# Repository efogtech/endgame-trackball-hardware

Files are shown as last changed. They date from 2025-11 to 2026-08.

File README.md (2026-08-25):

## Endgame Trackball (hardware)

| Revision | Type | RGB LEDs | Consumption (idle/sleep) | C‑to‑C cable support | Additional exposed pins* | Notes |
|---|---|---|---|---|---|---|
| rev3 | medium batch  | 🔴 | 🔴 480/130 uA | ⚠️ | ❌ | Doesn't support the new (latest) encoders without a firmware modification. |
| rev4 | large batch | 🟢 | 🔴 440/110 uA | ⚠️ | ❌ | — |
| rev5 | transitional  | 🟢 | 🟢 110/60 uA | ✅ | ❌ | Restarts when USB power lost. |
| rev6 | transitional  | 🟢 | 🟢 95/50 uA | ✅ | ⚠️ | The exposed pins are not very convenient to use. |
| rev7 | ~~final~~ | 🟢 | 🟢 95/50 uA | ✅ | ✅ | The AXP2585 charging IC has got discontinued. |
| rev8 | transitional  | 🟢 | ?/? uA | ✅ | ✅ | Specifications are to be measured. Has a [hardware issue](https://www.reddit.com/r/efogtech/comments/1vsg4g9/hardware_issue_disclosure/). Can't work without a battery. |
| rev9 | transitional  | 🟢 | ?/? uA | ✅ | ✅ | Specifications are to be measured. Has the same hardware issue. |
| rev10 | final | 🟢 | ?/? uA | ✅ | ✅ | Not in production yet. |

*Additional 3 GPIOs for arbitrary user modifications. 

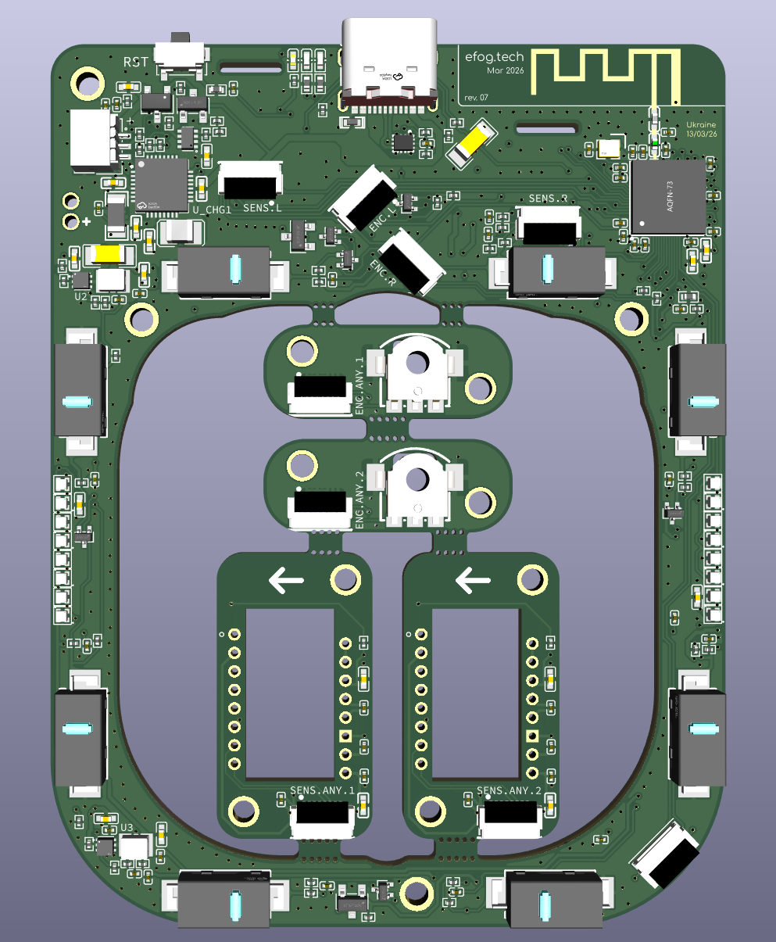
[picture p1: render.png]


#### Why 6 layers?

Because it's cheaper than 4 layers. Yes, seriously.

#### Stackup

JLC06161H-3313

#### Also see

Parent repo: https://github.com/efogtech/endgame-trackball

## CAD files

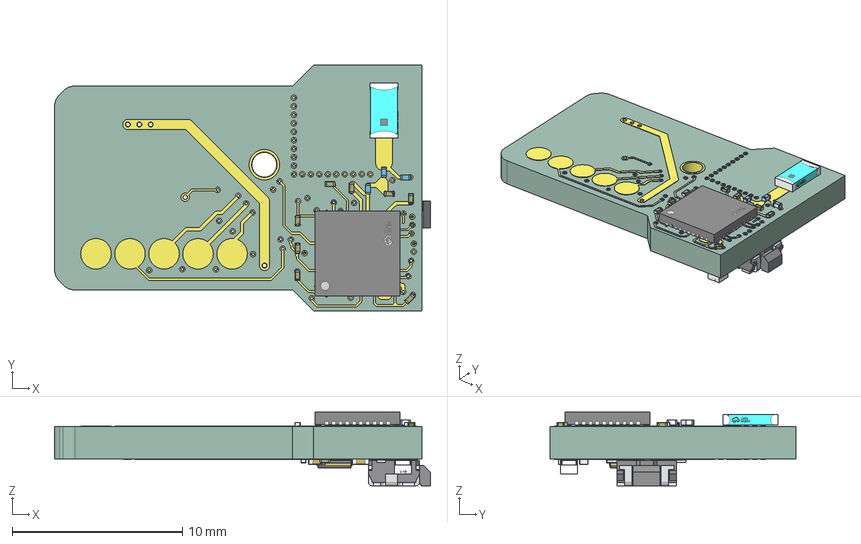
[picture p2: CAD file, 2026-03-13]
dongle-1k/dongle.step
22.1 x 14.4 x 4.33 mm
C0201_L0.6-W0.3-H0.3 x 12
L0201-RD x 3
ANT-SMD-2_L3.2-W1.6-H0.6-C504002
QFN-40_L5.0-W5.0-P0.40-TL-EP3.6
C0402_L1.0-W0.5-H0.5 x 3
CRYSTAL-SMD_4P-L2.0-W1.6-BL
SW-SMD_HX-TSC4A-250GF-DZ
LED-SMD_4P-L1.0-W1.0-TL_XL-1010RGBC-WS2812B
dongle_copper
dongle_via
dongle_PCB

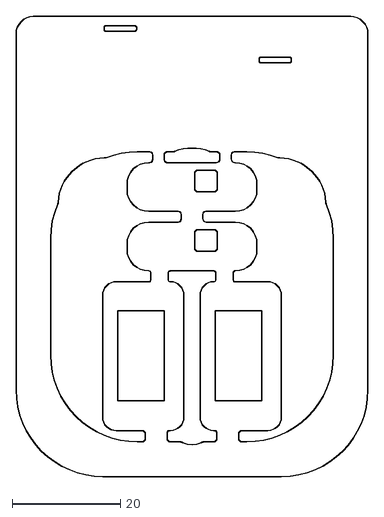
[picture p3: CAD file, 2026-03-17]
trackball-Edge_Cuts.dxf
65.0 x 85.0

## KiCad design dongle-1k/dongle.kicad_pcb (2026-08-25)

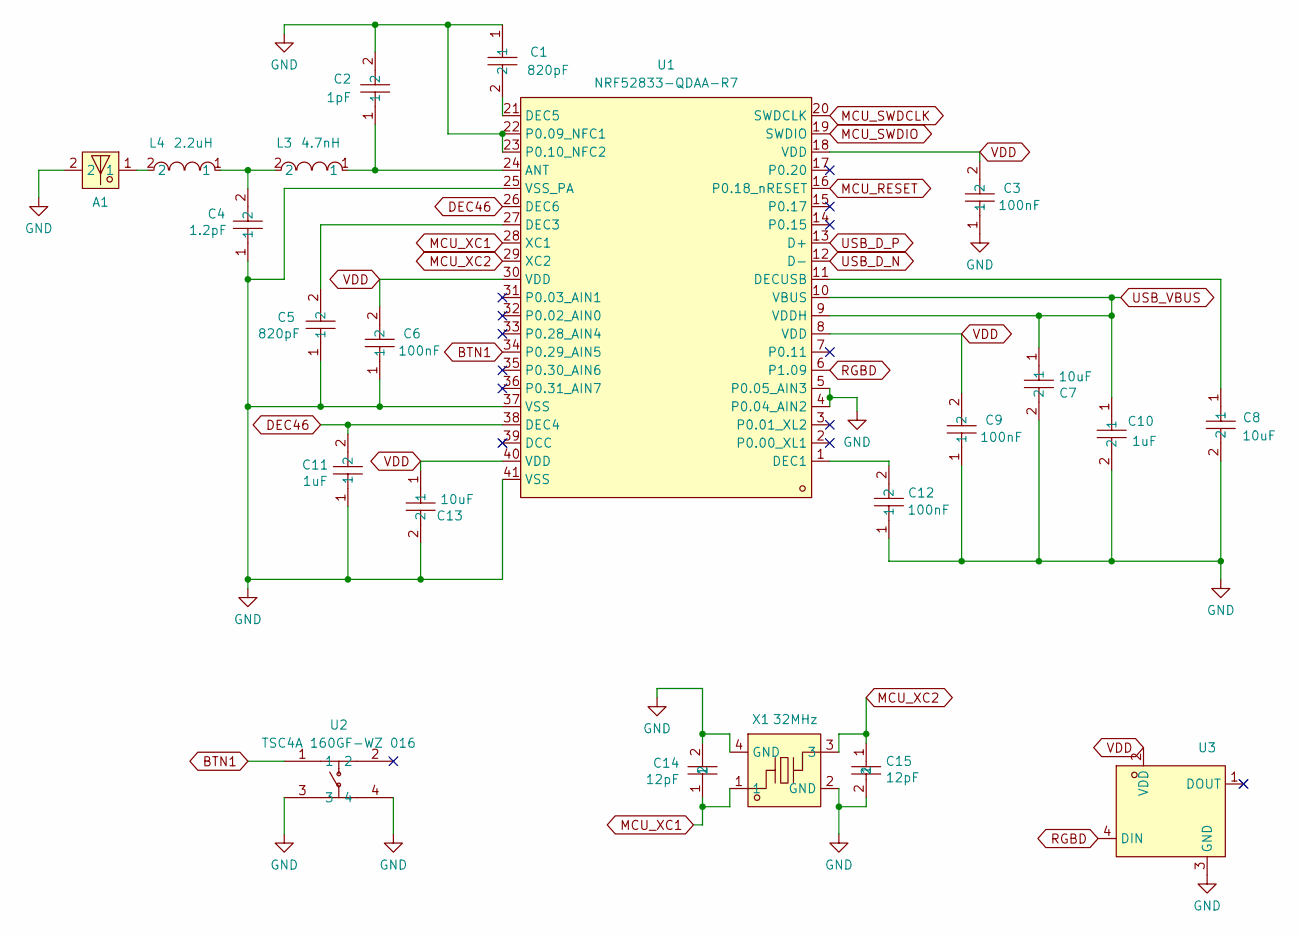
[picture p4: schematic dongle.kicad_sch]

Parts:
A1: mifa-2.4ghz-fr4-2.0mm
C1, C5: 0201B821K500NT; C0201; LCSC Part C2836759
C2: 0201CG1R0C250NT; C0201; LCSC Part C301901
C3, C6, C9, C12: CGA0201X5R104K100ET; C0201; LCSC Part C6119757
C4: CGA0201C0G1R2C500ET; C0201; LCSC Part C22374839
C7, C8, C13: CL05A106MP5NUNC_C315248; C0402; LCSC Part C315248
C10, C11: CGA0201X5R105M6R3ET; C0201; LCSC Part C6119749
C14, C15: 0201CG120J500NT; C0201; LCSC Part C50391
L3: LQP03HQ4N7H02D; L0201; LCSC Part C237443
L4: LQP03HQ2N2H02D; L0201; LCSC Part C1329438
U1: NRF52833-QDAA-R7; QFN-40_L5.0-W5.0-P0.40-TL-EP3.6; LCSC Part C3007767
U2: TSC4A 160GF-WZ 016; KEY-SMD_TSC4A; LCSC Part C2906284
U3: XL-1010RGBC-WS2812B; LED-SMD_4P-L1.0-W1.0-TL_XL-1010RGBC-WS2812B; LCSC Part C5349953
X1: XL7EL89CKI-111YLC-32M; CRYSTAL-SMD_4P-L2.0-W1.6-BL; LCSC Part C2965582

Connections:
BTN1: U1.34 (P0.29_AIN5), U2.1
DEC46: C11.2, U1.26 (DEC6), U1.38 (DEC4)
GND: A1.2, C1.1, C2.2, C3.1, C4.1, C5.1, C6.1, C7.2, C8.2, C9.1, C10.2, C11.1, C12.1, C13.2, C14.2, C15.2, U1.4 (P0.04_AIN2), U1.5 (P0.05_AIN3), U1.22 (P0.09_NFC1), U1.23 (P0.10_NFC2), U1.25 (VSS_PA), U1.37 (VSS), U1.41 (VSS), U2.3, U2.4, U3.1 (DOUT), U3.3 (GND), X1.2 (GND), X1.4 (GND)
MCU_RESET: U1.16 (P0.18_nRESET)
MCU_SWDCLK: U1.20 (SWDCLK)
MCU_SWDIO: U1.19 (SWDIO)
MCU_XC1: C14.1, U1.28 (XC1), X1.1
MCU_XC2: C15.1, U1.29 (XC2), X1.3
unnamed: A1.1, L4.2
unnamed: C4.2, L3.2, L4.1
unnamed: C2.1, L3.1, U1.24 (ANT)
unnamed: C12.2, U1.1 (DEC1)
unnamed: C5.2, U1.27 (DEC3)
unnamed: C1.2, U1.21 (DEC5)
unnamed: C8.1, U1.11 (DECUSB)
RGBD: U1.6 (P1.09), U3.4 (DIN)
USB_D_N: U1.12 (D-)
USB_D_P: U1.13 (D+)
USB_VBUS: C7.1, C10.1, U1.9 (VDDH), U1.10 (VBUS)
VDD: C3.2, C6.2, C9.2, C13.1, U1.8 (VDD), U1.18 (VDD), U1.30 (VDD), U1.40 (VDD), U3.2 (VDD)

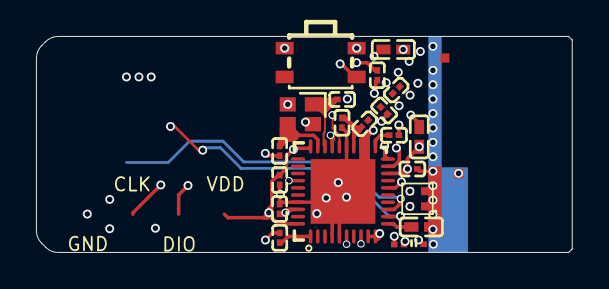
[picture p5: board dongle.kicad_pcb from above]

Board: 6 copper layers, 29.8 x 12.0 mm, 22 parts (0 on the bottom side), 15 nets.

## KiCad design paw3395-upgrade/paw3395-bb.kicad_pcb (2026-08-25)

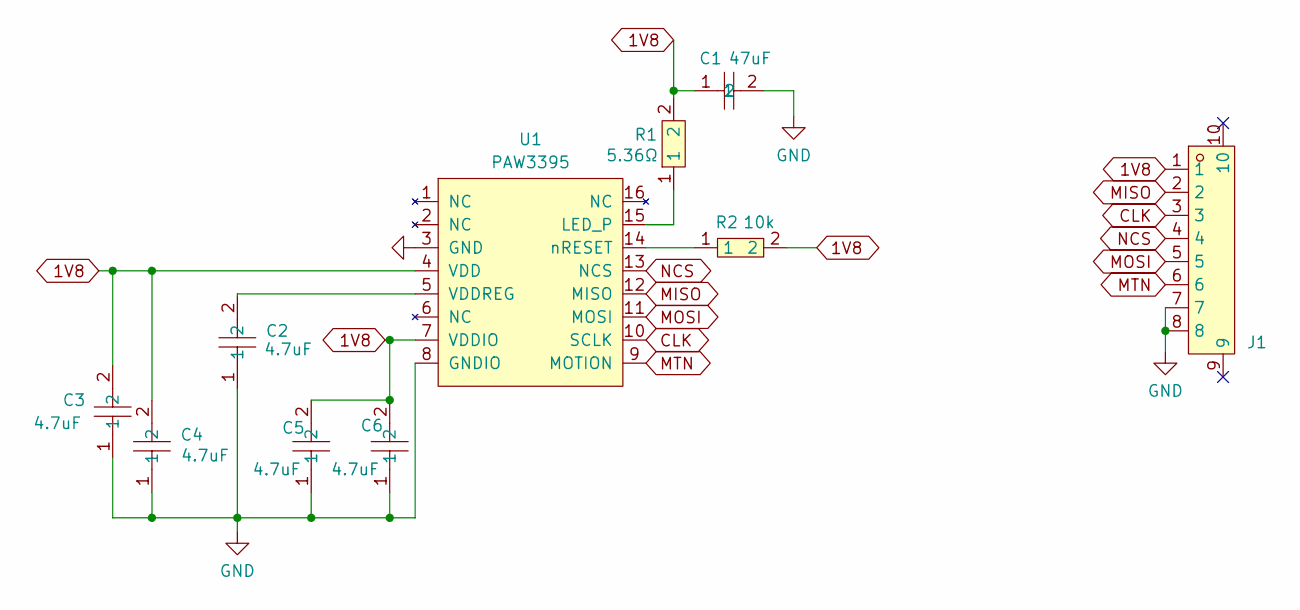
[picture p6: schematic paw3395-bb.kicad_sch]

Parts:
C1: GRM188R60J476ME15D; C0603; LCSC Part C140782
C2, C3, C4, C5, C6: GRM035R60J475ME15D; C0201; LCSC Part C335103
J1: AFH34-S08FIA-1H; FPC-SMD_8P-P0.50_JS_AFH34-S08FIA-1H; LCSC Part C5139822
R1: C49254122; R0402; LCSC Part C49254122
R2: RC-01W103JT; R0201; LCSC Part C304504
U1: PAW3395

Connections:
1V8: C1.1, C3.2, C4.2, C5.2, C6.2, J1.1, R1.2, R2.2, U1.4 (VDD), U1.7 (VDDIO)
CLK: J1.3, U1.10 (SCLK)
GND: C1.2, C2.1, C3.1, C4.1, C5.1, C6.1, J1.7, J1.8, U1.3 (GND), U1.8 (GNDIO)
MISO: J1.2, U1.12 (MISO)
MOSI: J1.5, U1.11 (MOSI)
MTN: J1.6, U1.9 (MOTION)
NCS: J1.4, U1.13 (NCS)
unnamed: R1.1, U1.15 (LED_P)
unnamed: C2.2, U1.5 (VDDREG)
unnamed: R2.1, U1.14 (nRESET)

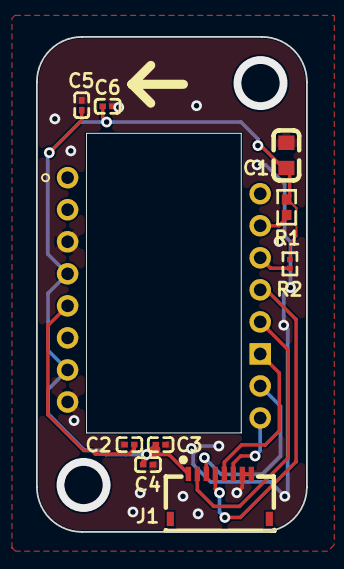
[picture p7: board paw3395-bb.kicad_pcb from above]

Board: 2 copper layers, 15.0 x 27.5 mm, 10 parts (0 on the bottom side), 10 nets.

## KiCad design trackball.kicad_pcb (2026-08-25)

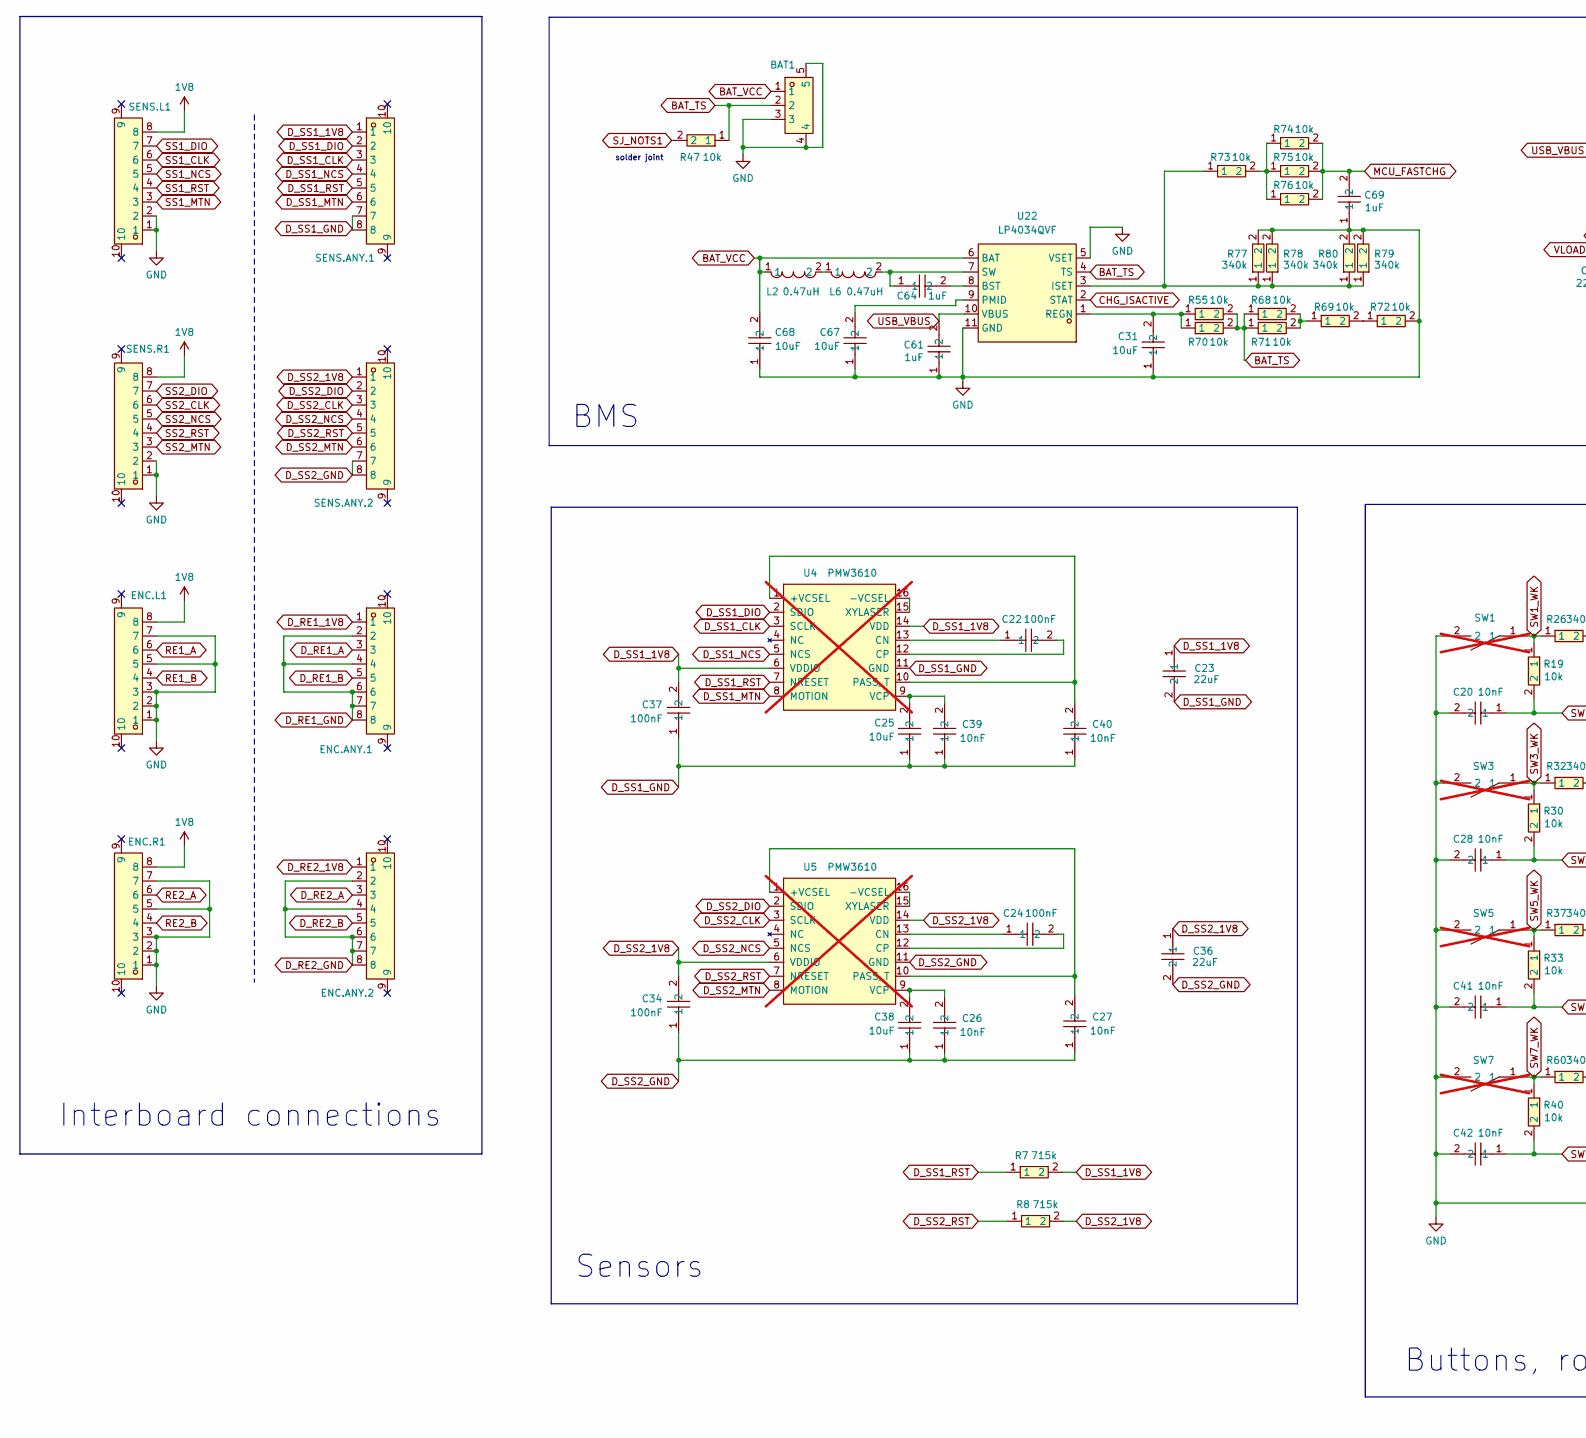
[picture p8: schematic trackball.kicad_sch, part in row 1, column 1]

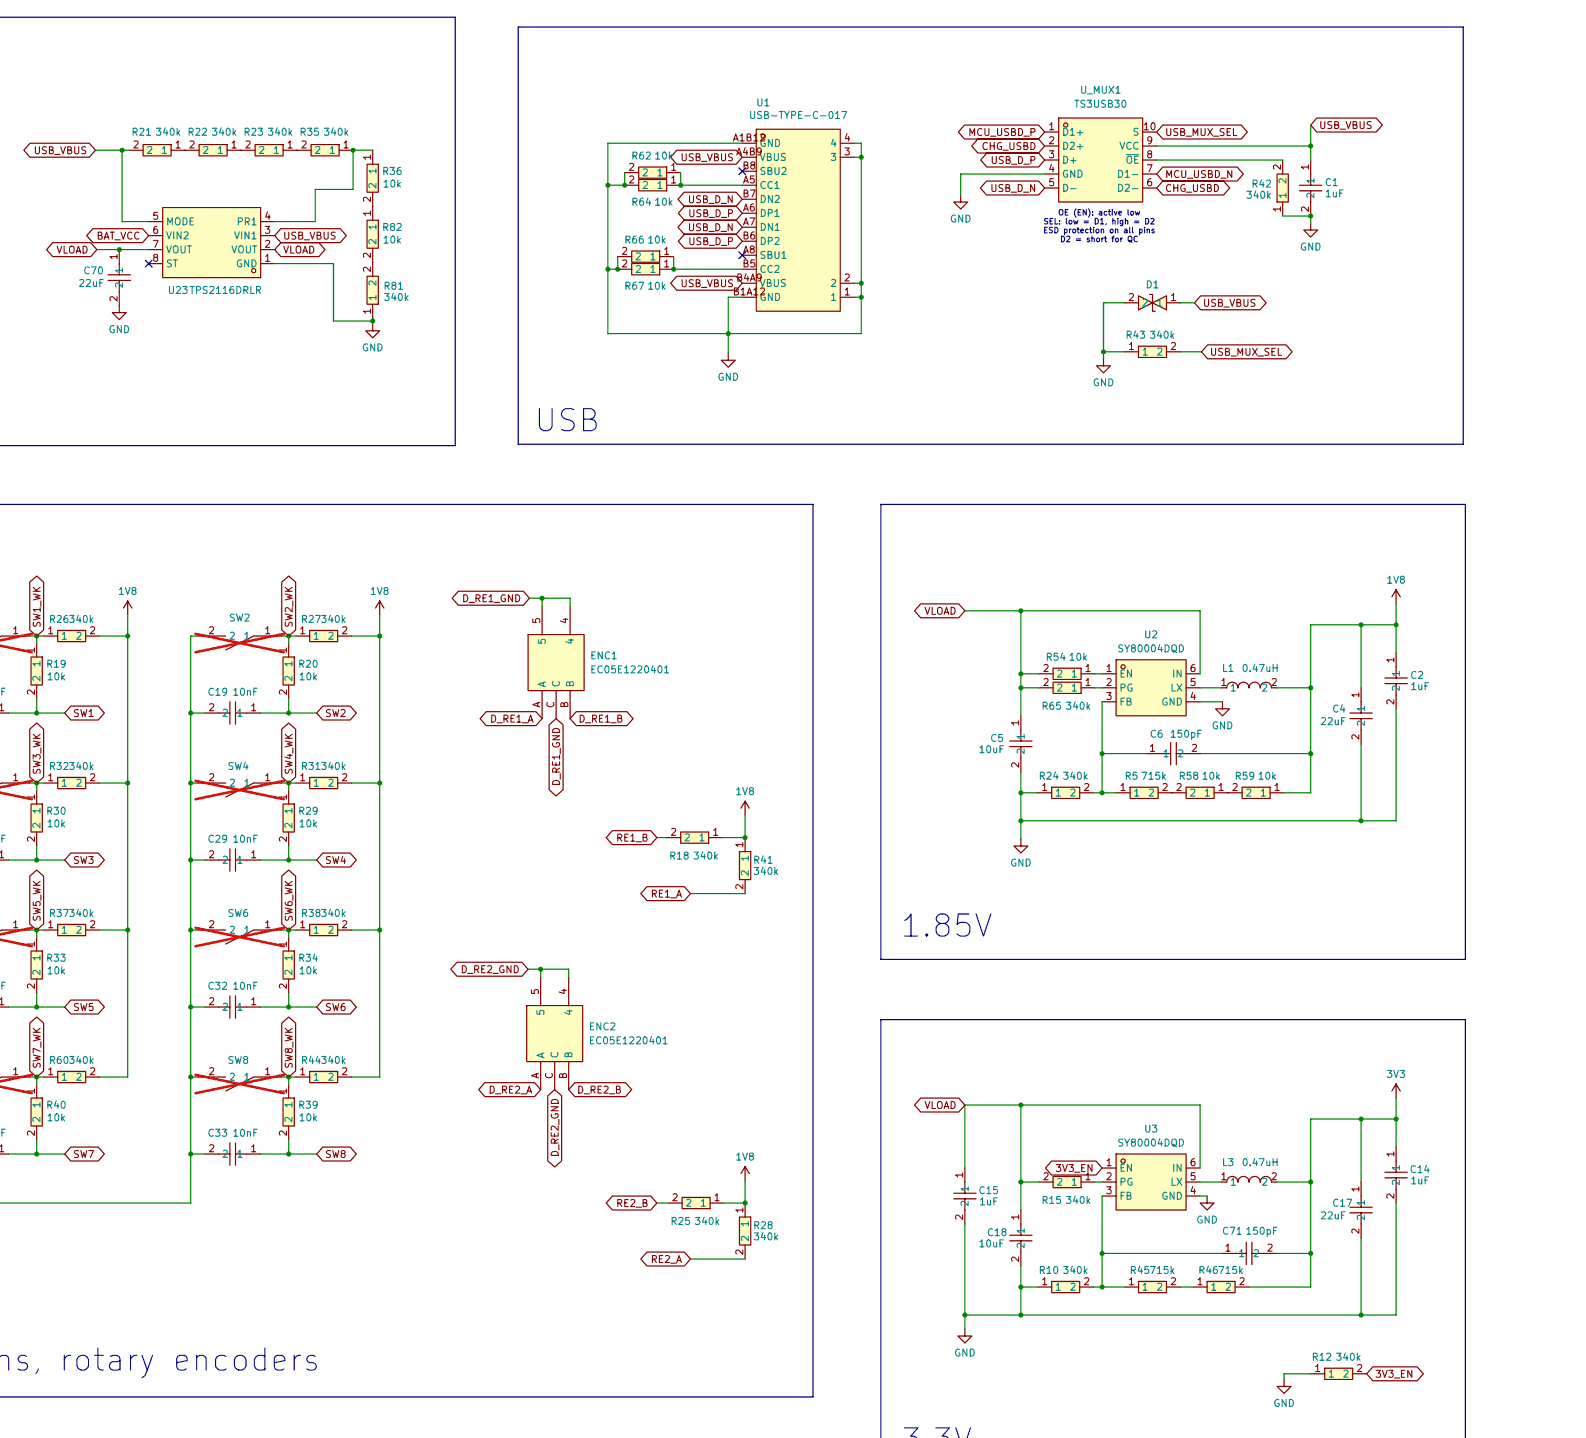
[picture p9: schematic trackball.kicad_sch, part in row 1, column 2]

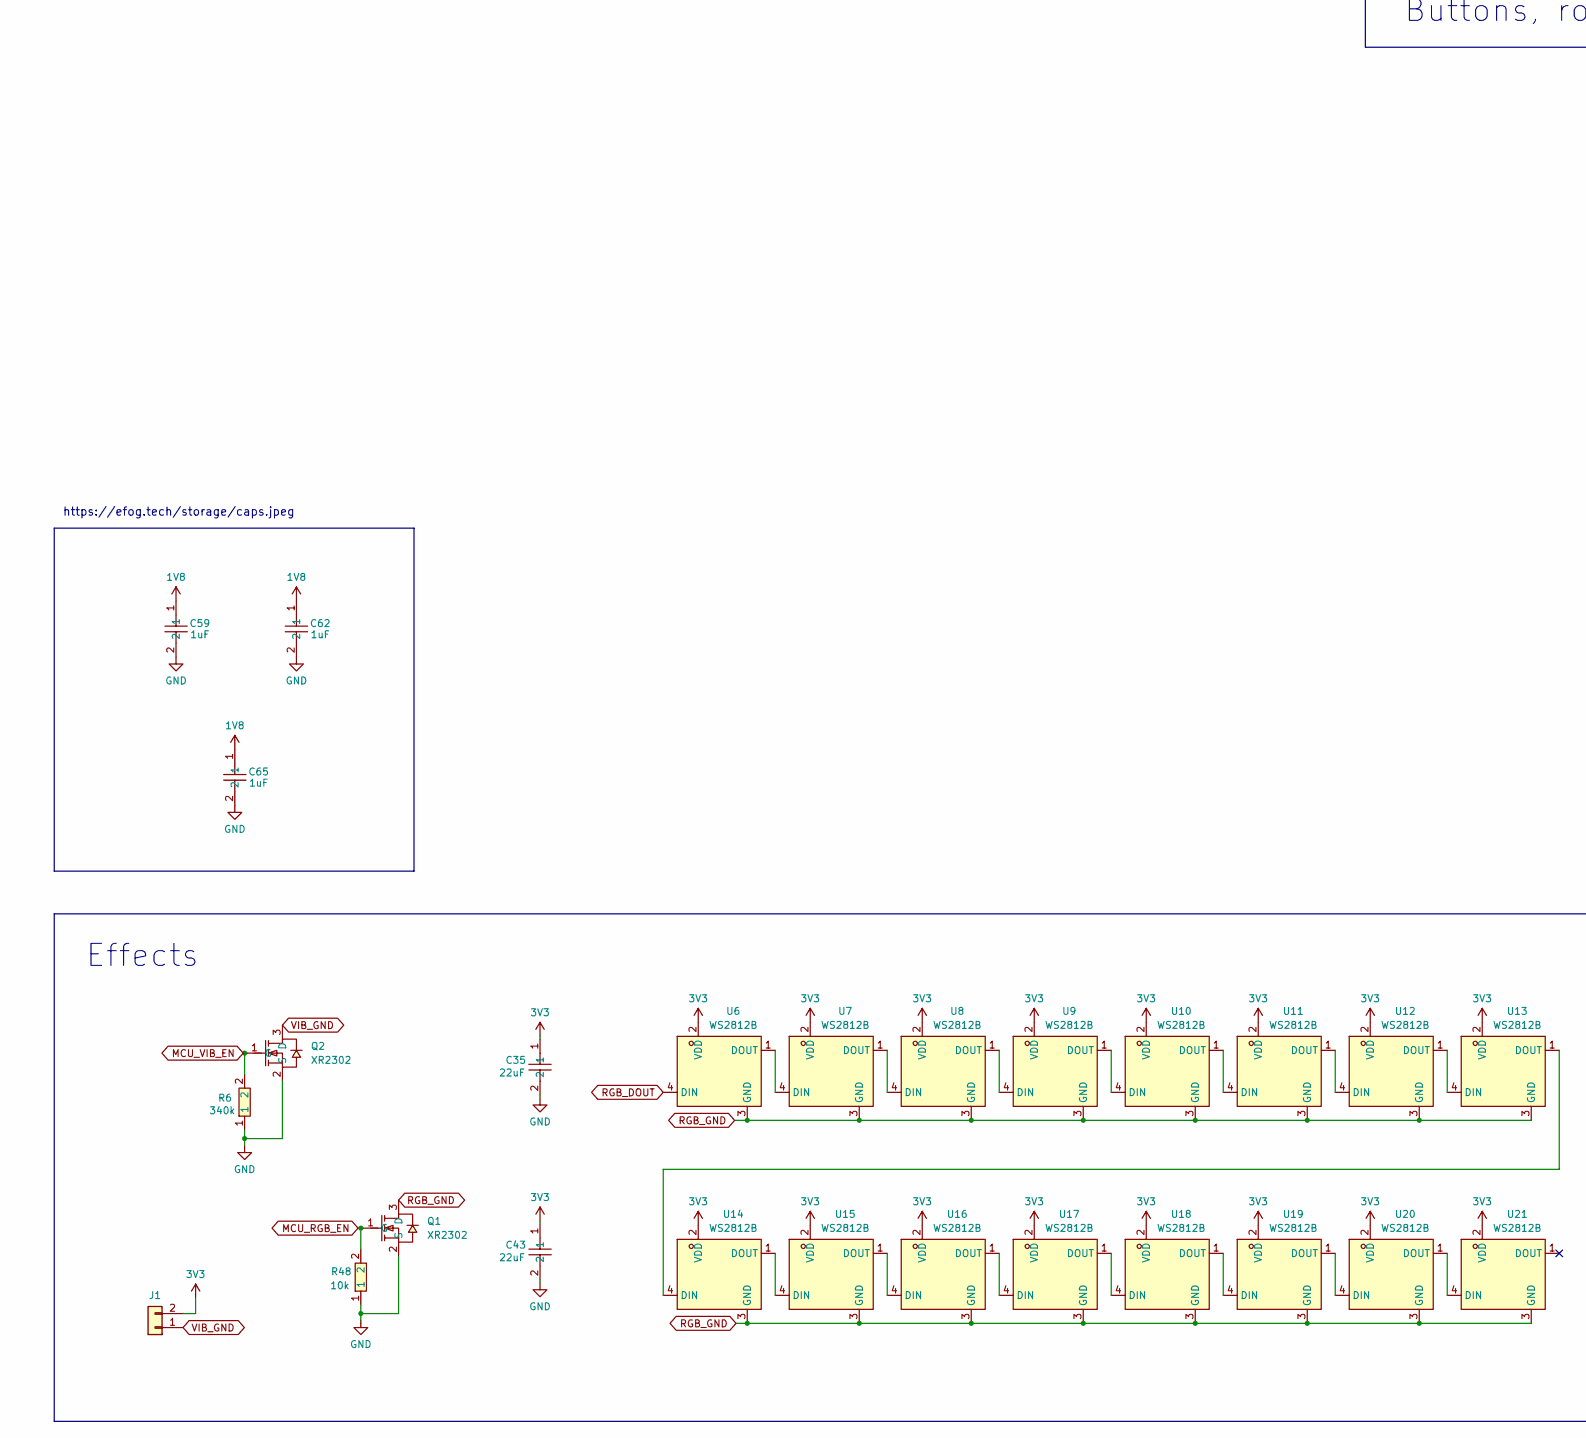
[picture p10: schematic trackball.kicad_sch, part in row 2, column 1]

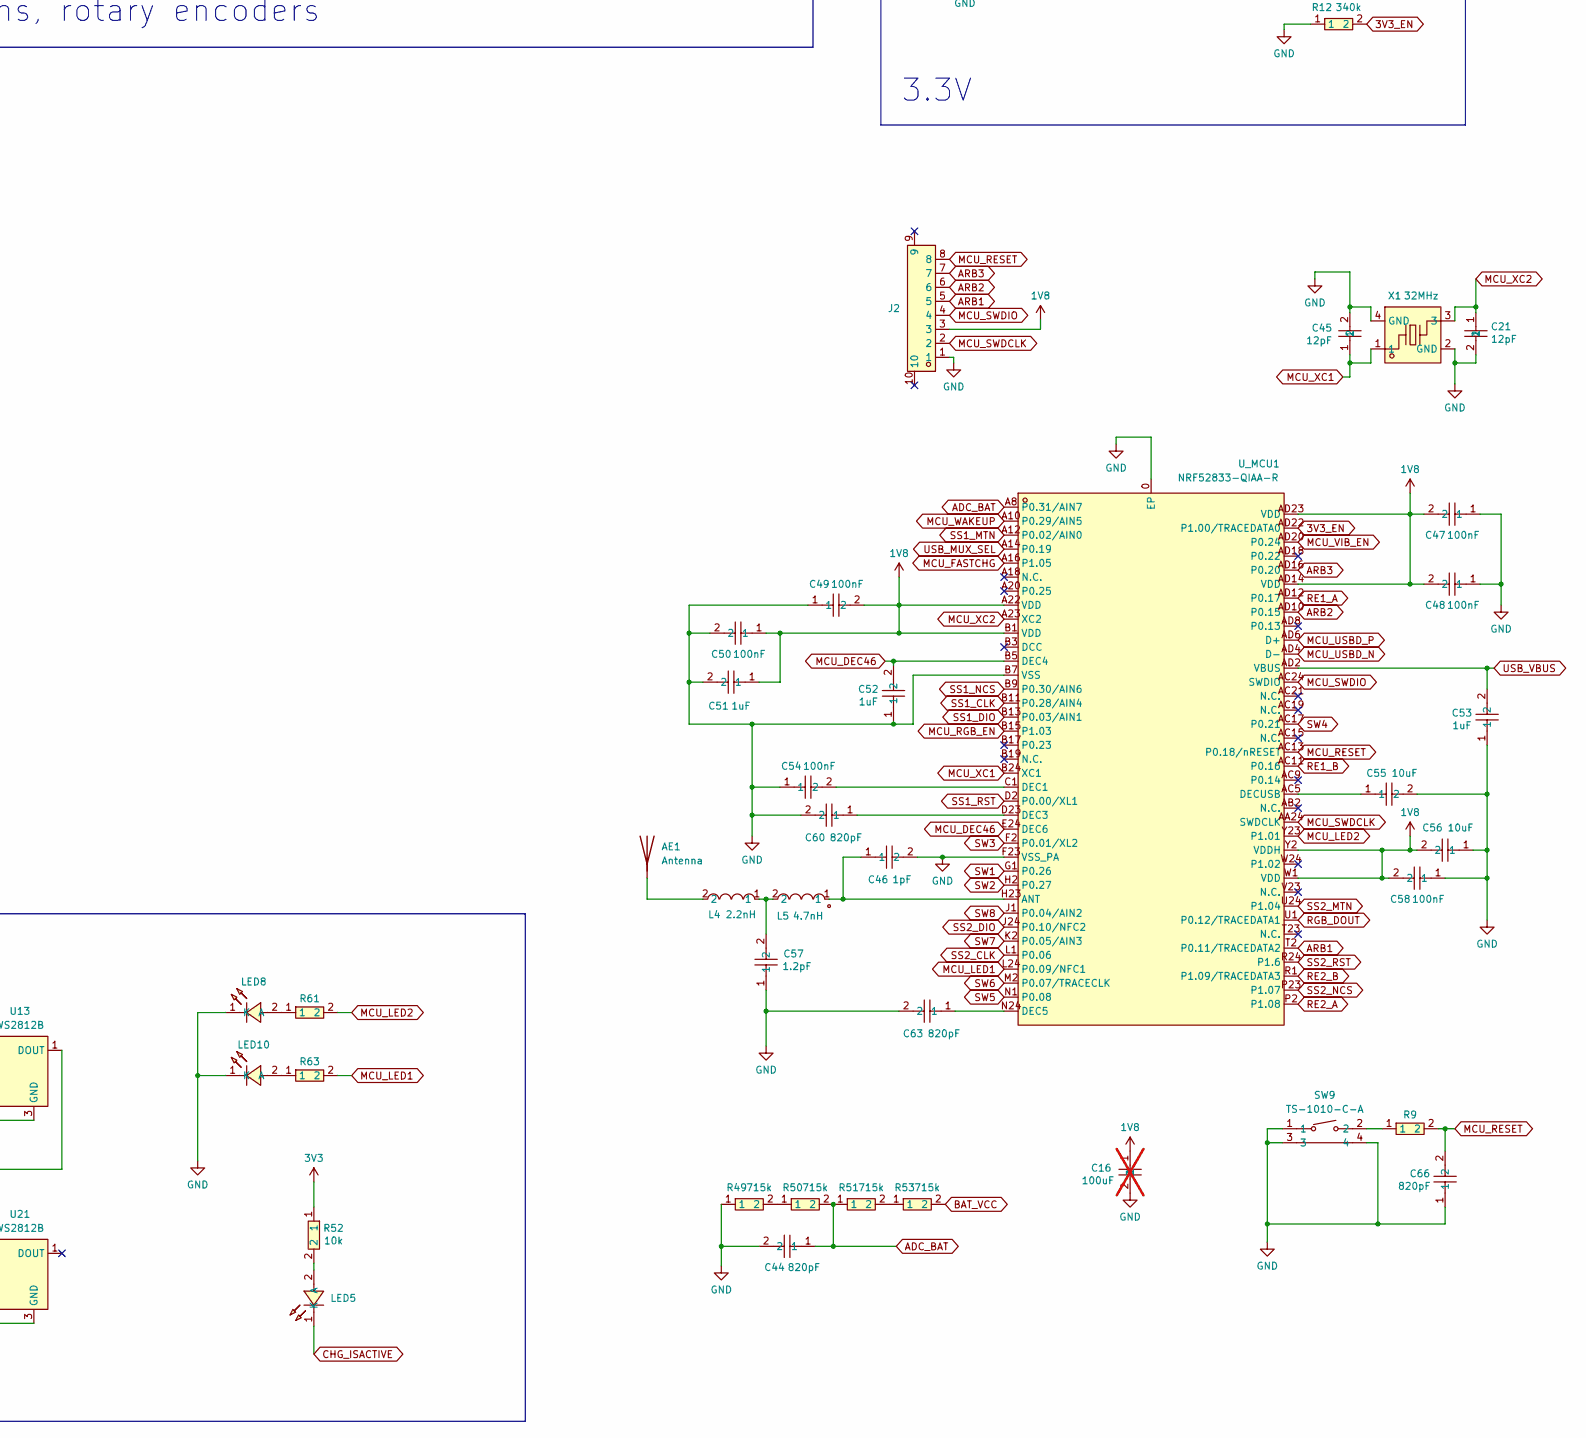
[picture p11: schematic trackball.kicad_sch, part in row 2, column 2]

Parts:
AE1: Antenna; Texas_SWRA117D_2.4GHz_Left
BAT1: HCZZ0032-3; CONN-SMD_HCZZ0032-3; LCSC Part C7433424
C1, C2, C14, C15, C51, C52, C53, C59, C61, C62, C64, C65, C69: CGA0201X5R105M6R3ET; C0201; LCSC Part C6119749
C4, C17, C23, C35, C36, C43, C70: GRM155R60J226ME11D; C0402; LCSC Part C415703
C5, C18, C25, C31, C38, C55, C56, C67, C68: CL05A106MP5NUNC_C315248; C0402; LCSC Part C315248
C6, C71: C0201; LCSC Part C18213206
C16: CL31A107MQHNNNE; C1206; LCSC Part C15008; not fitted
C19, C20, C26, C27, C28, C29, C32, C33, C39, C40, C41, C42: 0201B103K160NT; C0201; LCSC Part C285154
C21, C45: 0201CG120J500NT; C0201; LCSC Part C50391
C22, C24, C34, C37, C47, C48, C49, C50, C54, C58: CGA0201X5R104K100ET; C0201; LCSC Part C6119757
C44, C60, C63, C66: 0201B821K500NT; C0201; LCSC Part C2836759
C46: 0201CG1R0C250NT; C0201; LCSC Part C301901
C57: CGA0201C0G1R2C500ET; C0201; LCSC Part C22374839
D1: 0402ESDA-05N; D0402-BI; LCSC Part C316049
ENC1, ENC2: EC05E1220401; SW-SMD_EC05E1220401; LCSC Part C116648
ENC.ANY.1, ENC.ANY.2, ENC.L1, ENC.R1: AFH34-S08FIA-1H; FPC-SMD_8P-P0.50_JS_AFH34-S08FIA-1H; LCSC Part C5139822
J1: Conn_01x02
J2: AFH34-S08FIA-1H; FPC-SMD_8P-P0.50_JS_AFH34-S08FIA-1H; LCSC Part C5139822
L1, L2, L3, L6: FTC252012SR47MBCA; IND-SMD_L2.5-W2.0; LCSC Part C5832368
L4: LQG15HS2N2S02D; L0402; LCSC Part C86061
L5: LQG15HS4N7S02D; L0402-R-RD; LCSC Part C86065
LED5: XL-1005UGC; LED0402-RD_GREEN; LCSC Part C965793
LED8, LED10: TZ-P2-0402RTIA1-0.45T; LED0402-RD_RED; LCSC Part C779449
Q1, Q2: XR2302; SOT-23-3_L2.9-W1.3-P0.95-LS2.4-BR; LCSC Part C42456447
R5, R7, R8, R45, R46, R49, R50, R51, R53: 715k; R0201; LCSC Part C321023
R6, R10, R12, R15, R18, R21, R22, R23, R24, R25, R26, R27, R28, R31, R32, R35, R37, R38, R41, R42, R43, R44, R60, R65, R77, R78, R79, R80, R81: 0201WMF3403TEE; R0201; LCSC Part C423573
R9, R61, R63: RT0402BRE0750RL; R0402; LCSC Part C853312
R19, R20, R29, R30, R33, R34, R36, R39, R40, R47, R48, R52, R54, R55, R58, R59, R62, R64, R66, R67, R68, R69, R70, R71, R72, R73, R74, R75, R76, R82: 0201WMF1002TEE; R0201; LCSC Part C473048
SENS.ANY.1, SENS.ANY.2, SENS.L1, SENS.R1: AFH34-S08FIA-1H; FPC-SMD_8P-P0.50_JS_AFH34-S08FIA-1H; LCSC Part C5139822
SW1, SW2, SW3, SW4, SW5, SW6, SW7, SW8: HX TC-5608-Y; SW-SMD_TC-5608-Y; LCSC Part C25168853; not fitted
SW9: TS-1010-C-A; KEY-SMD_TX-1010-X-X; LCSC Part C692458
U1: USB-TYPE-C-017; USB-TYPE-C-SMD_C9900008089; LCSC Part C2927037
U2, U3: SY80004DQD; VSON-6_L1.5-W1.5-P0.50-TL; LCSC Part C20617244
U4, U5: PMW3610; not fitted
U6, U7, U8, U9, U10, U11, U12, U13, U14, U15, U16, U17, U18, U19, U20, U21: WS2812B; LED-SMD_4P-L1.0-W1.0-TL_XL-1010RGBC-WS2812B; LCSC Part C5349953
U22: LP4034QVF; DFN-10_L3.0-W3.0-P0.50-BL-EP2.5; MPN LP4034QVF; LCSC Part C42460070
U23: TPS2116DRLR; SOT-583-8_L2.1-W1.6-P0.50-LS1.6-BL; LCSC Part C3235557
U_MCU1: NRF52833-QIAA-R; AQFN-73_L7.0-W7.0-P0.50-BL-EP4.8; LCSC Part C504799
U_MUX1: TS3USB30; UQFN-10_L1.8-W1.4-P0.40-TL; LCSC Part C73880
X1: XL7EL89CKI-111YLC-32M; CRYSTAL-SMD_4P-L2.0-W1.6-BL; LCSC Part C2965582

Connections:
1V8: C2.1, C4.1, C6.2, C16.1, C47.2, C48.2, C49.2, C50.1, C51.1, C56.2, C58.2, C59.1, C62.1, C65.1, ENC.L1.8, ENC.R1.8, J2.3, L1.2, R18.1, R25.1, R26.2, R27.2, R28.1, R31.2, R32.2, R37.2, R38.2, R41.1, R44.2, R59.1, R60.2, SENS.L1.8, SENS.R1.8, U_MCU1.A22 (VDD), U_MCU1.AD14 (VDD), U_MCU1.AD23 (VDD), U_MCU1.B1 (VDD), U_MCU1.W1 (VDD), U_MCU1.Y2 (VDDH); also elsewhere on the board
3V3: C14.1, C17.1, C35.1, C43.1, C71.2, J1.2, L3.2, R46.2, R52.1, U6.2 (VDD), U7.2 (VDD), U8.2 (VDD), U9.2 (VDD), U10.2 (VDD), U11.2 (VDD), U12.2 (VDD), U13.2 (VDD), U14.2 (VDD), U15.2 (VDD), U16.2 (VDD), U17.2 (VDD), U18.2 (VDD), U19.2 (VDD), U20.2 (VDD), U21.2 (VDD)
3V3_EN: R12.2, U3.1 (EN), U_MCU1.AD22 (P1.00/TRACEDATA0)
ADC_BAT: C44.1, R50.2, R51.1, U_MCU1.A8 (P0.31/AIN7)
ARB1: J2.5, U_MCU1.T2 (P0.11/TRACEDATA2)
ARB2: J2.6, U_MCU1.AD10 (P0.15)
ARB3: J2.7, U_MCU1.AD16 (P0.20)
BAT_TS: BAT1.2, R47.1, R55.2, R68.1, R70.2, R71.1, U22.4 (TS)
BAT_VCC: BAT1.1, C68.2, L2.1, R53.2, U22.6 (BAT), U23.6 (VIN2)
CHG_ISACTIVE: LED5.1 (K), U22.2 (STAT)
CHG_USBD: U_MUX1.2 (D2+), U_MUX1.6 (D2-)
D_RE2_A: ENC1.A, ENC.ANY.1.3; also elsewhere on the board
D_RE2_B: ENC1.B, ENC.ANY.1.5; also elsewhere on the board
D_RE2_GND: ENC1.4, ENC1.5, ENC1.C, ENC.ANY.1.2, ENC.ANY.1.4, ENC.ANY.1.6, ENC.ANY.1.7, ENC.ANY.1.8; also elsewhere on the board
D_SS1_1V8: C23.1, C37.2, R7.2, SENS.ANY.1.1, U4.6 (VDDIO), U4.14 (VDD); also elsewhere on the board
D_SS1_CLK: SENS.ANY.1.3, U4.3 (SCLK); also elsewhere on the board
D_SS1_DIO: SENS.ANY.1.2, U4.2 (SDIO); also elsewhere on the board
D_SS1_GND: C23.2, C25.1, C37.1, C39.1, C40.1, SENS.ANY.1.7, SENS.ANY.1.8, U4.11 (GND); also elsewhere on the board
D_SS1_MTN: SENS.ANY.1.6, U4.8 (MOTION); also elsewhere on the board
D_SS1_NCS: SENS.ANY.1.4, U4.5 (NCS); also elsewhere on the board
D_SS1_RST: R7.1, SENS.ANY.1.5, U4.7 (NRESET); also elsewhere on the board
D_SS2_1V8: C34.2, C36.1, R8.2, SENS.ANY.2.1, U5.6 (VDDIO), U5.14 (VDD); also elsewhere on the board
D_SS2_CLK: SENS.ANY.2.3, U5.3 (SCLK); also elsewhere on the board
D_SS2_DIO: SENS.ANY.2.2, U5.2 (SDIO); also elsewhere on the board
D_SS2_GND: C26.1, C27.1, C34.1, C36.2, C38.1, SENS.ANY.2.7, SENS.ANY.2.8, U5.11 (GND); also elsewhere on the board
D_SS2_MTN: SENS.ANY.2.6, U5.8 (MOTION); also elsewhere on the board
D_SS2_NCS: SENS.ANY.2.4, U5.5 (NCS); also elsewhere on the board
D_SS2_RST: R8.1, SENS.ANY.2.5, U5.7 (NRESET); also elsewhere on the board
GND: BAT1.3, BAT1.4, BAT1.5, C1.2, C2.2, C4.2, C5.2, C14.2, C15.2, C16.2, C17.2, C18.2, C19.2, C20.2, C21.2, C28.2, C29.2, C31.1, C32.2, C33.2, C35.2, C41.2, C42.2, C43.2, C44.2, C45.2, C46.2, C47.1, C48.1, C49.1, C50.2, C51.2, C52.1, C53.1, C54.1, C55.2, C56.1, C57.1, C58.1, C59.2, C60.2, C61.1, C62.2, C63.2, C65.2, C66.1, C67.1, C68.1, C69.1, C70.2, D1.2, ENC.L1.1, ENC.L1.2, ENC.L1.3, ENC.L1.5, ENC.L1.7, ENC.R1.1, ENC.R1.2, ENC.R1.3, ENC.R1.5, ENC.R1.7, J2.1, LED8.1 (K), LED10.1 (K), Q1.2 (S), Q2.2 (S), R6.1, R10.1, R12.1, R24.1, R42.1, R43.1, R48.1, R49.1, R62.2, R64.2, R66.2, R67.2, R72.2, R77.2, R78.2, R79.2, R80.2, R81.1, SENS.L1.1, SENS.L1.2, SENS.R1.1, SENS.R1.2, SW1.2, SW2.2, SW3.2, SW4.2, SW5.2, SW6.2, SW7.2, SW8.2, SW9.1, SW9.3, SW9.4, U1.1, U1.2, U1.3, U1.4, U1.A1B12 (GND), U1.B1A12 (GND), U2.4 (GND), U3.4 (GND), U22.5 (VSET), U22.11 (GND), U23.1 (GND), U_MCU1.0 (EP), U_MCU1.B7 (VSS), U_MCU1.F23 (VSS_PA), U_MUX1.4 (GND), X1.2 (GND), X1.4 (GND); also elsewhere on the board
MCU_DEC46: C52.2, U_MCU1.B5 (DEC4), U_MCU1.E24 (DEC6)
MCU_FASTCHG: C69.2, R74.2, R75.2, R76.2, U_MCU1.A16 (P1.05)
MCU_LED1: R63.2, U_MCU1.L24 (P0.09/NFC1)
MCU_LED2: R61.2, U_MCU1.Y23 (P1.01)
MCU_RESET: C66.2, J2.8, R9.2, U_MCU1.AC13 (P0.18/nRESET)
MCU_RGB_EN: Q1.1 (G), R48.2, U_MCU1.B15 (P1.03)
MCU_SWDCLK: J2.2, U_MCU1.AA24 (SWDCLK)
MCU_SWDIO: J2.4, U_MCU1.AC24 (SWDIO)
MCU_USBD_N: U_MCU1.AD4 (D-), U_MUX1.7 (D1-)
MCU_USBD_P: U_MCU1.AD6 (D+), U_MUX1.1 (D1+)
MCU_VIB_EN: Q2.1 (G), R6.2, U_MCU1.AD20 (P0.24)
MCU_WAKEUP: U_MCU1.A10 (P0.29/AIN5); also elsewhere on the board
MCU_XC1: C45.1, U_MCU1.B24 (XC1), X1.1
MCU_XC2: C21.1, U_MCU1.A23 (XC2), X1.3
unnamed: AE1.1 (A_1), L4.2
unnamed: C57.2, L4.1, L5.2
unnamed: ENC2.4, ENC2.5, ENC2.C, ENC.ANY.2.2, ENC.ANY.2.4, ENC.ANY.2.6, ENC.ANY.2.7, ENC.ANY.2.8
unnamed: ENC2.A, ENC.ANY.2.3
unnamed: ENC2.B, ENC.ANY.2.5
unnamed: L2.2, L6.1
unnamed: LED5.2 (A), R52.2
unnamed: LED8.2 (A), R61.1
unnamed: LED10.2 (A), R63.1
unnamed: R5.2, R58.2
unnamed: R9.1, SW9.2
unnamed: R21.1, R22.2
unnamed: R22.1, R23.2
unnamed: R23.1, R35.2
unnamed: R36.2, R82.1
unnamed: R45.2, R46.1
unnamed: R49.2, R50.1
unnamed: R51.2, R53.1
unnamed: R58.1, R59.2
unnamed: R68.2, R69.1, R71.2
unnamed: R69.2, R72.1
unnamed: R73.2, R74.1, R75.1, R76.1
unnamed: R81.2, R82.2
unnamed: R62.1, R64.1, U1.A5 (CC1)
unnamed: R66.1, R67.1, U1.B5 (CC2)
unnamed: R54.1, U2.1 (EN)
unnamed: C6.1, R5.1, R24.2, U2.3 (FB)
unnamed: L1.1, U2.5 (LX)
unnamed: R65.1, U2.2 (PG)
unnamed: C71.1, R10.2, R45.1, U3.3 (FB)
unnamed: L3.1, U3.5 (LX)
unnamed: R15.1, U3.2 (PG)
unnamed: C40.2, U4.1 (+VCSEL), U4.10 (PASS_T)
unnamed: U4.15 (XYLASER), U4.16 (-VCSEL)
unnamed: C22.1, U4.13 (CN)
unnamed: C22.2, U4.12 (CP)
unnamed: C25.2, C39.2, U4.9 (VCP)
unnamed: C27.2, U5.1 (+VCSEL), U5.10 (PASS_T)
unnamed: U5.15 (XYLASER), U5.16 (-VCSEL)
unnamed: C24.1, U5.13 (CN)
unnamed: C24.2, U5.12 (CP)
unnamed: C26.2, C38.2, U5.9 (VCP)
unnamed: U6.1 (DOUT), U7.4 (DIN)
unnamed: U7.1 (DOUT), U8.4 (DIN)
unnamed: U8.1 (DOUT), U9.4 (DIN)
unnamed: U9.1 (DOUT), U10.4 (DIN)
unnamed: U10.1 (DOUT), U11.4 (DIN)
unnamed: U11.1 (DOUT), U12.4 (DIN)
unnamed: U12.1 (DOUT), U13.4 (DIN)
unnamed: U13.1 (DOUT), U14.4 (DIN)
unnamed: U14.1 (DOUT), U15.4 (DIN)
unnamed: U15.1 (DOUT), U16.4 (DIN)
unnamed: U16.1 (DOUT), U17.4 (DIN)
unnamed: U17.1 (DOUT), U18.4 (DIN)
unnamed: U18.1 (DOUT), U19.4 (DIN)
unnamed: U19.1 (DOUT), U20.4 (DIN)
unnamed: U20.1 (DOUT), U21.4 (DIN)
unnamed: C64.2, U22.8 (BST)
unnamed: R73.1, R77.1, R78.1, R79.1, R80.1, U22.3 (ISET)
unnamed: C67.2, U22.9 (PMID)
unnamed: C31.2, R55.1, R70.1, U22.1 (REGN)
unnamed: C64.1, L6.2, U22.7 (SW)
unnamed: R35.1, R36.1, U23.4 (PR1)
unnamed: C46.1, L5.1, U_MCU1.H23 (ANT)
unnamed: C54.2, U_MCU1.C1 (DEC1)
unnamed: C60.1, U_MCU1.D23 (DEC3)
unnamed: C63.1, U_MCU1.N24 (DEC5)
unnamed: C55.1, U_MCU1.AC5 (DECUSB)
unnamed: R42.2, U_MUX1.8 (~OE)
RE1_A: ENC.L1.6, R41.2, U_MCU1.AD12 (P0.17); also elsewhere on the board
RE1_B: ENC.L1.4, R18.2, U_MCU1.AC11 (P0.16); also elsewhere on the board
RE2_A: ENC.R1.6, R28.2, U_MCU1.P2 (P1.08); also elsewhere on the board
RE2_B: ENC.R1.4, R25.2, U_MCU1.R1 (P1.09/TRACEDATA3); also elsewhere on the board
RGB_DOUT: U6.4 (DIN), U_MCU1.U1 (P0.12/TRACEDATA1)
RGB_GND: Q1.3 (D), U6.3 (GND), U7.3 (GND), U8.3 (GND), U9.3 (GND), U10.3 (GND), U11.3 (GND), U12.3 (GND), U13.3 (GND), U14.3 (GND), U15.3 (GND), U16.3 (GND), U17.3 (GND), U18.3 (GND), U19.3 (GND), U20.3 (GND), U21.3 (GND)
SJ_NOTS1: R47.2
SS1_CLK: SENS.L1.6, U_MCU1.B11 (P0.28/AIN4); also elsewhere on the board
SS1_DIO: SENS.L1.7, U_MCU1.B13 (P0.03/AIN1); also elsewhere on the board
SS1_MTN: SENS.L1.3, U_MCU1.A12 (P0.02/AIN0); also elsewhere on the board
SS1_NCS: SENS.L1.5, U_MCU1.B9 (P0.30/AIN6); also elsewhere on the board
SS1_RST: SENS.L1.4, U_MCU1.D2 (P0.00/XL1); also elsewhere on the board
SS2_CLK: SENS.R1.6, U_MCU1.L1 (P0.06); also elsewhere on the board
SS2_DIO: SENS.R1.7, U_MCU1.J24 (P0.10/NFC2); also elsewhere on the board
SS2_MTN: SENS.R1.3, U_MCU1.U24 (P1.04); also elsewhere on the board
SS2_NCS: SENS.R1.5, U_MCU1.P23 (P1.07); also elsewhere on the board
SS2_RST: SENS.R1.4, U_MCU1.R24 (P1.6); also elsewhere on the board
SW1: C20.1, R19.2, U_MCU1.G1 (P0.26)
SW1_WK: R19.1, R26.1, SW1.1; also elsewhere on the board
SW2: C19.1, R20.2, U_MCU1.H2 (P0.27)
SW2_WK: R20.1, R27.1, SW2.1; also elsewhere on the board
SW3: C28.1, R30.2, U_MCU1.F2 (P0.01/XL2)
SW3_WK: R30.1, R32.1, SW3.1; also elsewhere on the board
SW4: C29.1, R29.2, U_MCU1.AC17 (P0.21)
SW4_WK: R29.1, R31.1, SW4.1; also elsewhere on the board
SW5: C41.1, R33.2, U_MCU1.N1 (P0.08)
SW5_WK: R33.1, R37.1, SW5.1; also elsewhere on the board
SW6: C32.1, R34.2, U_MCU1.M2 (P0.07/TRACECLK)
SW6_WK: R34.1, R38.1, SW6.1; also elsewhere on the board
SW7: C42.1, R40.2, U_MCU1.K2 (P0.05/AIN3)
SW7_WK: R40.1, R60.1, SW7.1; also elsewhere on the board
SW8: C33.1, R39.2, U_MCU1.J1 (P0.04/AIN2)
SW8_WK: R39.1, R44.1, SW8.1; also elsewhere on the board
USB_D_N: U1.A7 (DN1), U1.B7 (DN2), U_MUX1.5 (D-)
USB_D_P: U1.A6 (DP1), U1.B6 (DP2), U_MUX1.3 (D+)
USB_MUX_SEL: R43.2, U_MCU1.A14 (P0.19), U_MUX1.10 (S)
USB_VBUS: C1.1, C53.2, C61.2, D1.1, R21.2, U1.A4B9 (VBUS), U1.B4A9 (VBUS), U22.10 (VBUS), U23.3 (VIN1), U23.5 (MODE), U_MCU1.AD2 (VBUS), U_MUX1.9 (VCC)
VIB_GND: J1.1, Q2.3 (D)
VLOAD: C5.1, C15.1, C18.1, C70.1, R15.2, R54.2, R65.2, U2.6 (IN), U3.6 (IN), U23.2 (VOUT), U23.7 (VOUT)

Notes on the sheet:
Effects
Interboard connections
Buttons, rotary encoders
BMS
USB
https://efog.tech/storage/caps.jpeg
3.3V
Sensors
solder joint
1.85V
OE (EN): active low SEL: low = D1, high = D2 ESD protection on all pins D2 = short for QC

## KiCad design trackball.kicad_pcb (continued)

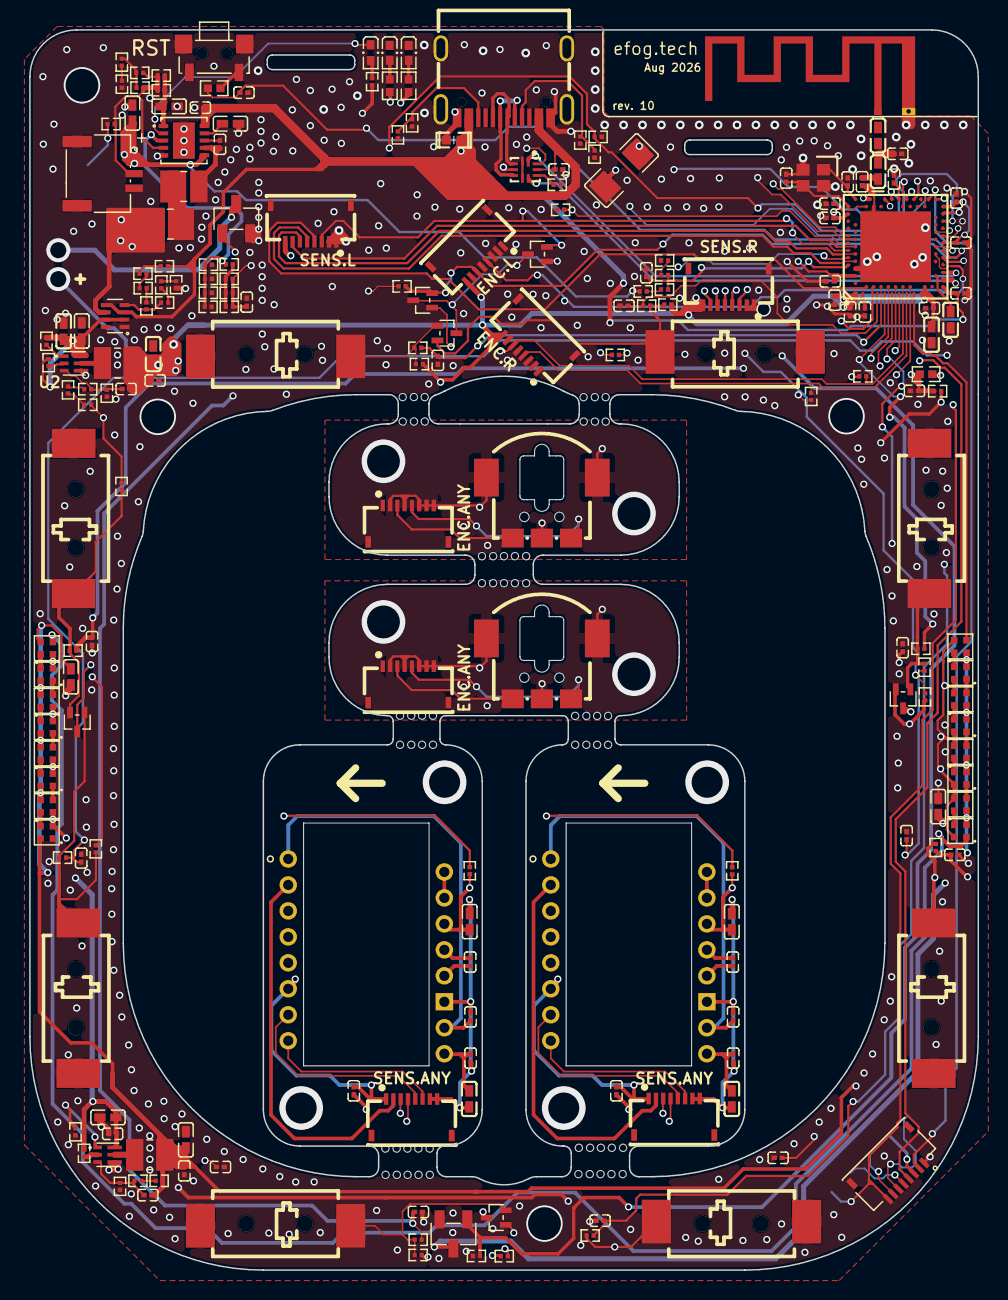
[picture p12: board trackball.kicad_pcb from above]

Board: 6 copper layers, 65.0 x 85.0 mm, 202 parts (0 on the bottom side), 150 nets.

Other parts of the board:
C30: 0201B821K500NT; C0201
D2, D3, D4, D5, D6, D7: BAS40-06T-7-F; SC-75-3_L1.6-W0.8-P1.00-LS1.6-BR
ENC1#2: EC05E1220401; SW-SMD_EC05E1220401
ENC.ANY, ENC.ANY#2, ENC.L, ENC.R: AFH34-S08FIA-1H; FPC-SMD_8P-P0.50_JS_AFH34-S08FIA-1H
R56: RT0402BRE0750RL; R0402
R57: 0201WMF1002TEE; R0201
SENS.ANY, SENS.ANY#2, SENS.L, SENS.R: AFH34-S08FIA-1H; FPC-SMD_8P-P0.50_JS_AFH34-S08FIA-1H

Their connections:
1V8: ENC.L.8, ENC.R.8, R57.2, SENS.L.8, SENS.R.8; also elsewhere on the board
D_RE1_A: ENC1#2.A, ENC.ANY.3
D_RE1_B: ENC1#2.B, ENC.ANY.5
D_RE1_GND: ENC1#2.4, ENC1#2.5, ENC1#2.C, ENC.ANY.2, ENC.ANY.4, ENC.ANY.6, ENC.ANY.7, ENC.ANY.8
D_RE2_A: ENC.ANY#2.3; also elsewhere on the board
D_RE2_B: ENC.ANY#2.5; also elsewhere on the board
D_RE2_GND: ENC.ANY#2.2, ENC.ANY#2.4, ENC.ANY#2.6, ENC.ANY#2.7, ENC.ANY#2.8; also elsewhere on the board
D_SS1_1V8: SENS.ANY.1; also elsewhere on the board
D_SS1_CLK: SENS.ANY.3; also elsewhere on the board
D_SS1_DIO: SENS.ANY.2; also elsewhere on the board
D_SS1_GND: SENS.ANY.7, SENS.ANY.8; also elsewhere on the board
D_SS1_MTN: SENS.ANY.6; also elsewhere on the board
D_SS1_NCS: SENS.ANY.4; also elsewhere on the board
D_SS1_RST: SENS.ANY.5; also elsewhere on the board
D_SS2_1V8: SENS.ANY#2.1; also elsewhere on the board
D_SS2_CLK: SENS.ANY#2.3; also elsewhere on the board
D_SS2_DIO: SENS.ANY#2.2; also elsewhere on the board
D_SS2_GND: SENS.ANY#2.7, SENS.ANY#2.8; also elsewhere on the board
D_SS2_MTN: SENS.ANY#2.6; also elsewhere on the board
D_SS2_NCS: SENS.ANY#2.4; also elsewhere on the board
D_SS2_RST: SENS.ANY#2.5; also elsewhere on the board
GND: C30.2, ENC.L.1, ENC.L.2, ENC.L.3, ENC.L.5, ENC.L.7, ENC.R.1, ENC.R.2, ENC.R.3, ENC.R.5, ENC.R.7, SENS.L.1, SENS.L.2, SENS.R.1, SENS.R.2, SENS.R.10; also elsewhere on the board
MCU_WAKEUP: C30.1, R56.1, R57.1; also elsewhere on the board
unnamed: D2.3, D3.3, D4.3, D5.3, D6.3, D7.3, R56.2
RE1_A: D7.2, ENC.L.6; also elsewhere on the board
RE1_B: ENC.L.4; also elsewhere on the board
RE2_A: D7.1, ENC.R.6; also elsewhere on the board
RE2_B: ENC.R.4; also elsewhere on the board
SS1_CLK: SENS.L.6; also elsewhere on the board
SS1_DIO: SENS.L.7; also elsewhere on the board
SS1_MTN: D6.2, SENS.L.3; also elsewhere on the board
SS1_NCS: SENS.L.5; also elsewhere on the board
SS1_RST: SENS.L.4; also elsewhere on the board
SS2_CLK: SENS.R.6; also elsewhere on the board
SS2_DIO: SENS.R.7; also elsewhere on the board
SS2_MTN: D6.1, SENS.R.3; also elsewhere on the board
SS2_NCS: SENS.R.5; also elsewhere on the board
SS2_RST: SENS.R.4; also elsewhere on the board
SW1_WK: D2.2; also elsewhere on the board
SW2_WK: D2.1; also elsewhere on the board
SW3_WK: D3.2; also elsewhere on the board
SW4_WK: D3.1; also elsewhere on the board
SW5_WK: D4.2; also elsewhere on the board
SW6_WK: D4.1; also elsewhere on the board
SW7_WK: D5.2; also elsewhere on the board
SW8_WK: D5.1; also elsewhere on the board

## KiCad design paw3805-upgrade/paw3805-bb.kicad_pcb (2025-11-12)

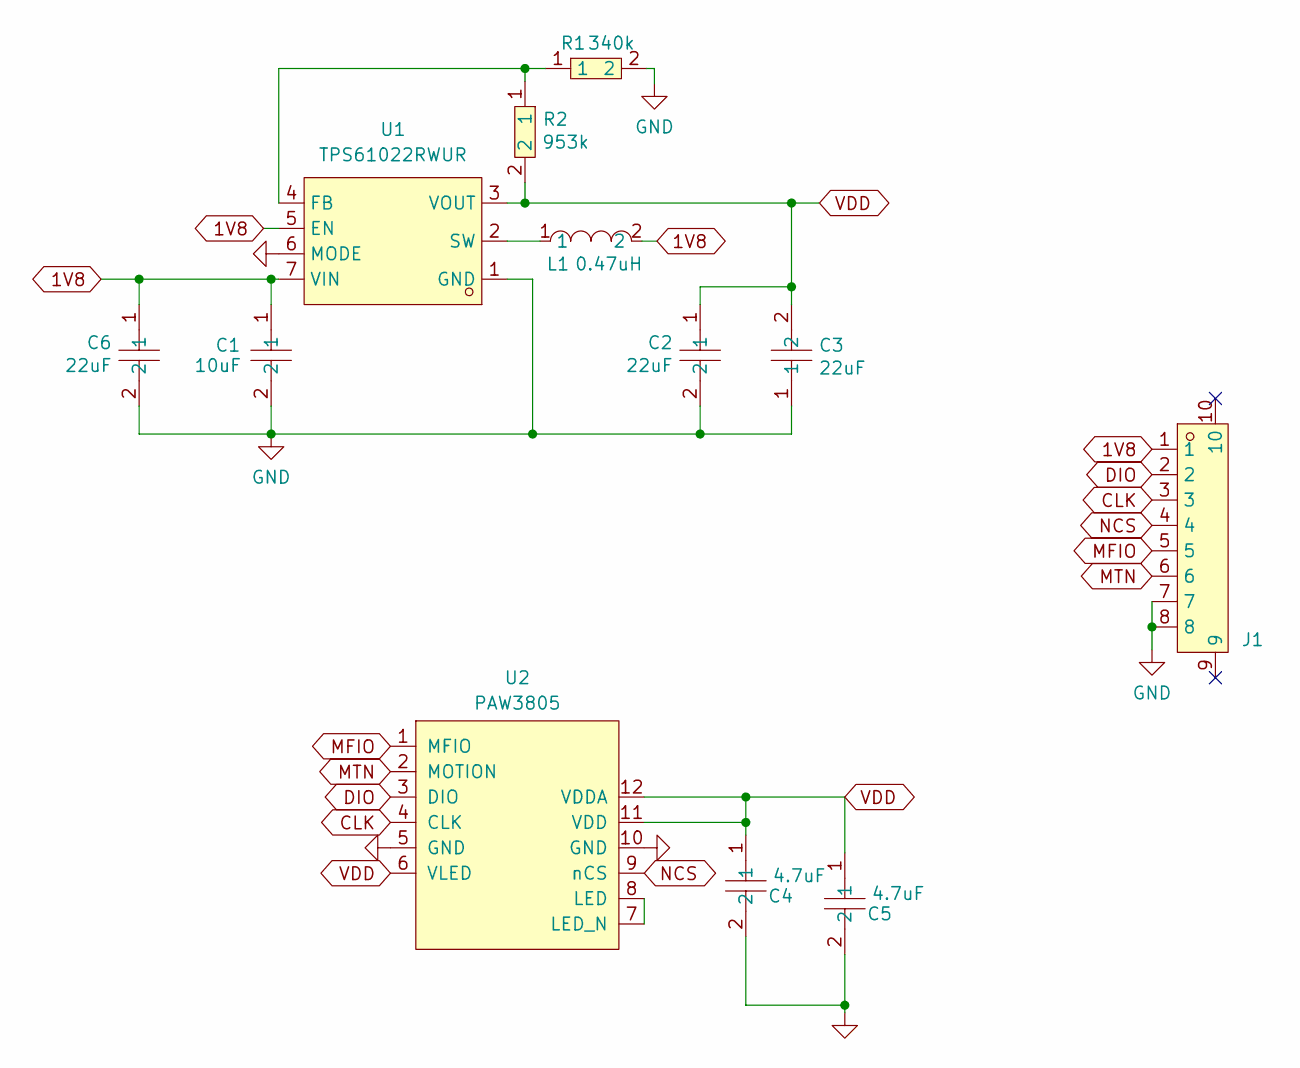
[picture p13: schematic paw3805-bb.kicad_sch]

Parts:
C1: CL05A106MP5NUNC_C315248; C0402; LCSC Part C315248
C2, C3, C6: GRM155R60J226ME11D; C0402; LCSC Part C415703
C4, C5: GRM035R60J475ME15D; C0201; LCSC Part C335103
J1: AFH34-S08FIA-1H; FPC-SMD_8P-P0.50_JS_AFH34-S08FIA-1H; LCSC Part C5139822
L1: FTC252012SR47MBCA; IND-SMD_L2.5-W2.0; LCSC Part C5832368
R1: RC-01W103JT; R0201; LCSC Part C320848
R2: RTT019533FTH; R0201; LCSC Part C166079
U1: TPS61022RWUR; VQFN-7_L2.0-W2.0-P0.55-TL_RWU; LCSC Part C915088
U2: PAW3805

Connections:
1V8: C1.1, C6.1, J1.1, L1.2, U1.5 (EN), U1.7 (VIN)
CLK: J1.3, U2.4 (CLK)
DIO: J1.2, U2.3 (DIO)
GND: C1.2, C2.2, C3.1, C4.2, C5.2, C6.2, J1.7, J1.8, R1.2, U1.1 (GND), U1.6 (MODE), U2.5 (GND), U2.10 (GND)
MFIO: J1.5, U2.1 (MFIO)
MTN: J1.6, U2.2 (MOTION)
NCS: J1.4, U2.9 (nCS)
unnamed: R1.1, R2.1, U1.4 (FB)
unnamed: L1.1, U1.2 (SW)
unnamed: U2.7 (LED_N), U2.8 (LED)
VDD: C2.1, C3.2, C4.1, C5.1, R2.2, U1.3 (VOUT), U2.6 (VLED), U2.11 (VDD), U2.12 (VDDA)

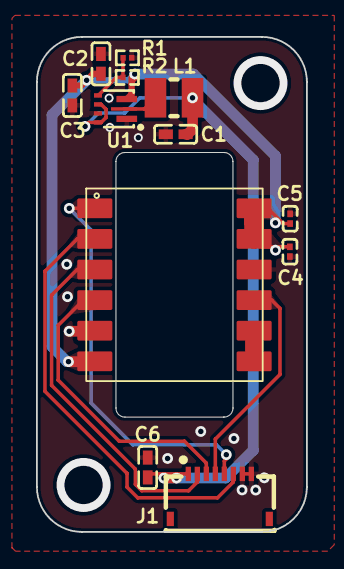
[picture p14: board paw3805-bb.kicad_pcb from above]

Board: 2 copper layers, 15.0 x 27.5 mm, 12 parts (0 on the bottom side), 11 nets.

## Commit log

2025-10-07 feat: rev.04 WIP
    [trackball.kicad_pcb, trackball.kicad_sch]
2025-10-16 feat: rev.04 hardware
    [trackball.kicad_pcb, trackball.kicad_sch]
2025-10-16 chore: assembly guide improvement
2025-10-16 bugfix: 3d models
    [trackball.kicad_pcb]
2025-11-12 feat: encoders upgrade; PAW3395 bb; PAW3805 bb
    [encoders_upgrade.kicad_pcb, encoders_upgrade.kicad_sch, panel.kicad_pcb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]
2025-12-15 feat: dongle
    [dongle.kicad_pcb, dongle.kicad_sch]
2026-01-21 feat: 1k dongle, rev5 hw (wip)
    [dongle.kicad_pcb, dongle.kicad_sch, trackball.kicad_pcb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]
2026-01-22 chore: rev5 hw fixes
    [trackball.kicad_pcb]
2026-03-13 feat: rev7 hardware
    [dongle.kicad_pcb, dongle.step, paw3395-bb.kicad_pcb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]
2026-03-17 feat: rev7 hardware (final)
    [trackball-Edge_Cuts.dxf, trackball.kicad_pcb, trackball.kicad_sch]
2026-03-23 chore: tidy
    [trackball.kicad_pcb]
2026-08-25 feat: rev10 hardware
    [dongle.kicad_pcb, dongle.kicad_sch, paw3395-bb.kicad_pcb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]
